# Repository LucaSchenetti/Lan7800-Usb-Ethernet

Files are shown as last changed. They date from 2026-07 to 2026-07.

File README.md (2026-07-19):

# USB SuperSpeed 3.1 → Gigabit Ethernet (LAN7800)

USB 3.1 Gen 1 (SuperSpeed, 5 Gbit/s) → Gigabit Ethernet adapter based on the
**Microchip LAN7800T/VSX** controller. The board has a **USB-C female** input
and a **USB-A male** output, so it works with both modern USB-C and traditional
USB-A ports. This repository contains the PCB design, production files, and
throughput test results measured with `iperf3`.

*(Versione italiana più in basso — [Italiano](#-adattatore-usb-superspeed-31--gigabit-ethernet-lan7800))*

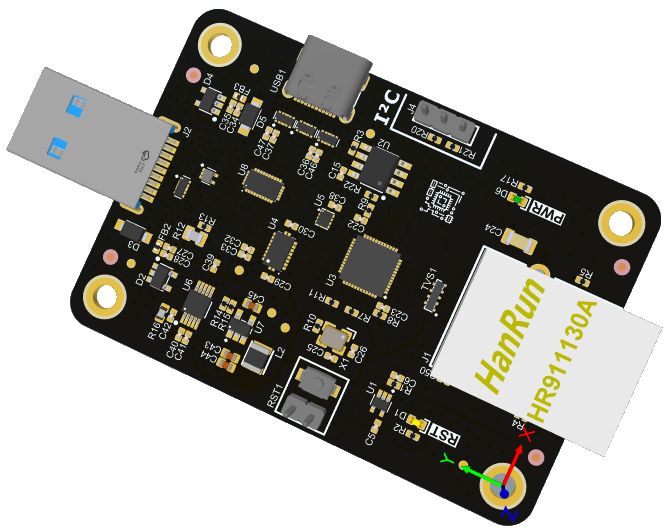
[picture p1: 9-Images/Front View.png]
Front render


## Features

- **Microchip LAN7800T/VSX** — USB 3.1 Gen 1 → 10/100/1000 Mbit/s Ethernet controller
- **USB-C female** input and **USB-A male** output — works with both modern
  USB-C ports and traditional USB-A ports
- **HanRun HR911130A** integrated RJ45 jack with magnetics
- Link negotiated at **1000 Mbit/s full-duplex**
- **Line-rate** throughput in both directions (see results below)
- On-board **reset button**, **power LED**, and an **I²C header** (SDA/SCL/GND)
- Bus-powered via USB
- Revision **C** (07/2026)

## Connectors and main components

The board accepts a **USB-C (female)** input and provides a **USB-A (male)**
output. The USB-C side includes full orientation/CC handling:

| Component | Function |
|---|---|
| Microchip **LAN7800T/VSX** | USB 3.1 Gen 1 → Gigabit Ethernet controller |
| Microchip **93AA66C-I/SN** | 4 Kbit serial EEPROM — stores the MAC address and USB configuration (VID/PID, descriptors) for the LAN7800 |
| TI **HD3SS3220RNHR** | USB-C mux/switch with CC logic — handles cable orientation and port role (DRP/DFP/UFP) for the USB-C connector |
| Diodes **PI3USB302-AZBEX** | USB Type-C SuperSpeed data demux/switch — routes the SS lines according to plug orientation |
| TI **TS3USB221ARSER** | USB 2.0 (high-speed) data mux/switch — routes the D+/D− lines according to plug orientation |
| HanRun **HR911130A** | Integrated RJ45 connector with Ethernet magnetics |

Additional on-board features: **RST** reset button, **PWR** power LED, and a
3-pin **I²C** header (SDA / SCL / GND) for debugging or expansion.

## Board

| Front (render) | Back (render) |
|:---:|:---:|
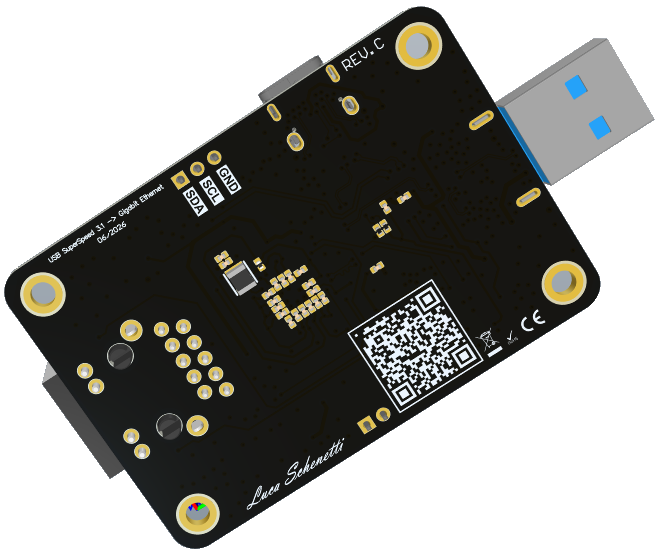
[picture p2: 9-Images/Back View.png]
Back render
| Front render |  |

| Front (photo) | Back (photo) |
|:---:|:---:|
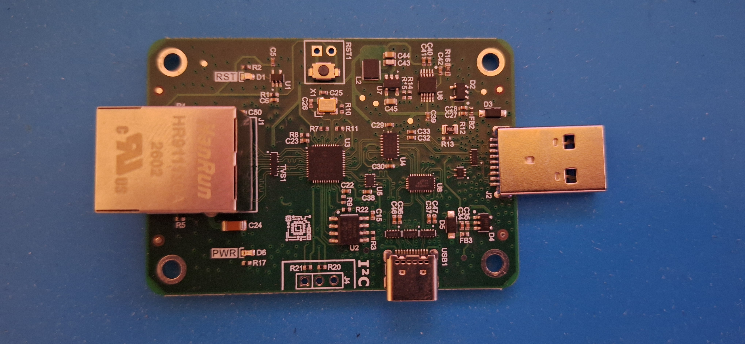
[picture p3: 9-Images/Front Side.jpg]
Front photo
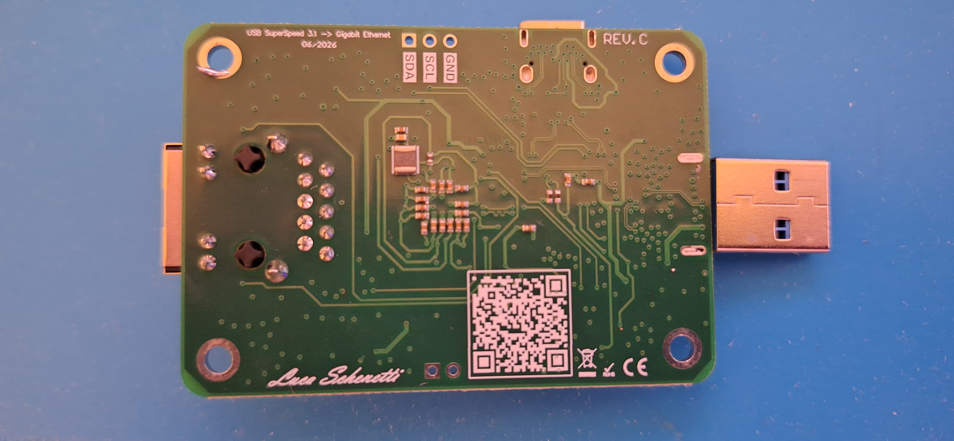
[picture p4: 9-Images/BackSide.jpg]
Back photo
|  |  |

## Test results (iperf3)

Tests were run with the [`iperf_benchmark.py`](8-Test_PCB/iperf_benchmark.py) script
included in this repository. The adapter reaches Gigabit Ethernet line rate
(~949 Mbit/s, the practical maximum with standard MTU due to protocol overhead)
in a stable way and with low host CPU usage.

### Windows 11 (bare-metal)

**Test host:** Windows 11 · iperf3 3.21 (64-bit) · server `11.0.0.91`
**Adapter:** LAN7800T/VSX · USB 3.1 · link 1000/full

| Test | Throughput | Notes |
|---|---|---|
| TCP unidirectional TX | 949 Mbit/s | min/max 947/950 · CPU client 3% / server 10% |
| TCP unidirectional RX | 949 Mbit/s | min/max 944/950 · CPU client 21% / server 7% |
| TCP 4 parallel streams | 949 Mbit/s | min/max 946/956 · CPU client 3% / server 12% |
| UDP (1000M) | 956 Mbit/s | jitter 0.02 ms · packet loss 0.06% |

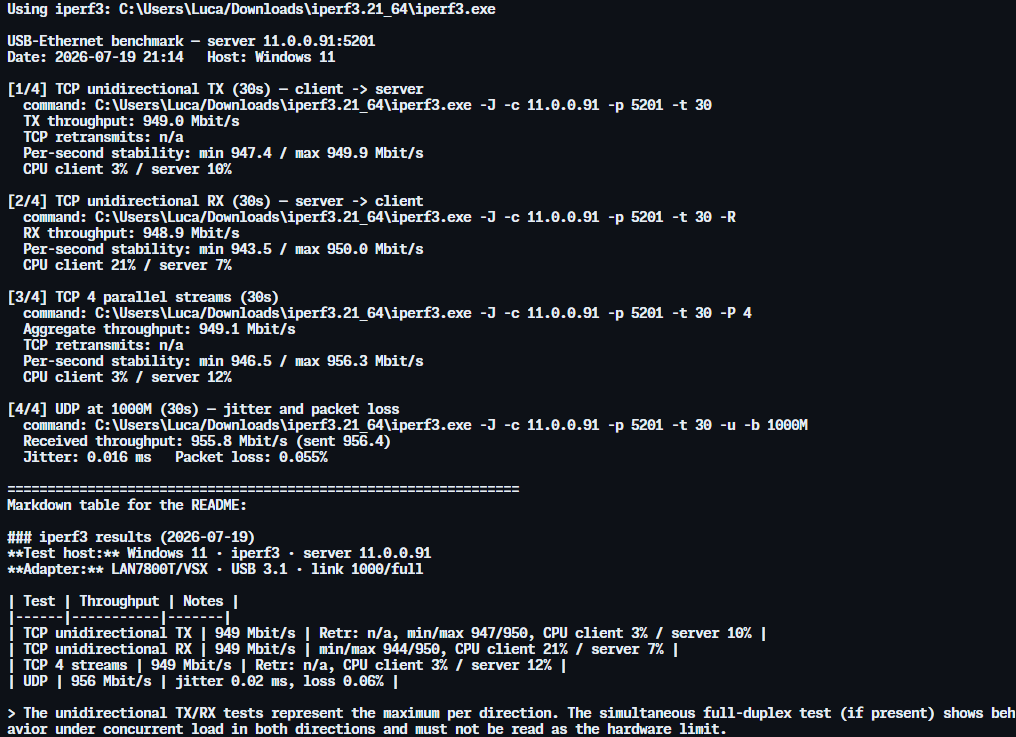
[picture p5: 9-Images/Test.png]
Benchmark output


**How to read the results:**

- **Unidirectional TX and RX** represent the maximum per single direction. Both
  are at line rate (~949 Mbit/s) and stable for the whole test duration, with no
  drop over time.
- **Low host CPU** (3–21%): throughput is not CPU-limited. USB→Ethernet adapters
  have no hardware offload, so this is a good efficiency indicator.
- **0.02 ms jitter** and **0.06% packet loss** on UDP saturated at 1 Gbit/s
  indicate an electrically clean link.
- TCP retransmits (`Retr`) are not reported on Windows because the field is not
  populated by the platform in the JSON output; this is normal and not a problem.

> **Note on simultaneous full-duplex:** a `--bidir` test (traffic in both
> directions at the same time) shows an asymmetry between TX and RX. This is the
> expected behavior of a USB→Ethernet adapter: without hardware offload, the two
> directions share the USB bus and CPU, and one prevails over the other under
> concurrent load. **This is not a hardware limit** — measured individually,
> both directions reach line rate, as shown in the table.

## Reproducing the tests

You need a second machine acting as the iperf3 server:

```bash
# On the server machine
iperf3 -s
```

```bash
# On the client machine (with the adapter under test)
python iperf_benchmark.py <SERVER_IP> --duration 30 --chip "LAN7800T/VSX · USB 3.1 · link 1000/full"
```

Useful options:

- `--duration N` — duration of the unidirectional TCP tests (default 60s)
- `--quick` — short 10s tests for a quick check
- `--bidir` — adds the simultaneous full-duplex test (extra, requires iperf3 ≥ 3.7)
- `--streams N` — number of parallel streams (default 4)
- `--iperf3 PATH` — path to the executable if not in PATH

The script prints the results and generates a Markdown table ready to paste.

### Notes on the test environment

For reliable numbers, run the tests from a **bare-metal operating system**, not
from a virtual machine. In a VM, hypervisor scheduling and virtual networking
can introduce throughput drops and asymmetries unrelated to the hardware under
test. The results above come from Windows 11 installed directly on the PC.

## Repository contents

```
Lan7800-Usb-Ethernet/
├── 1-Draw/                  Altium project — schematics (.SchDoc) and PCB layout (.PcbDoc)
├── 3-Gerber File & BOM/     Gerber files (Rev. A/B/C), BOM and pick-and-place (CPL)
├── 5-Driver/               EEPROM images (MAC address / USB configuration)
├── 7-Spec/                 Component datasheets (LAN7800, HD3SS3220, ...)
├── 8-Test_PCB/             iperf3 benchmark script and its README
├── 9-Images/               Board renders and photos
├── LICENSE
└── README.md
```

The Altium `History/` folder (automatic backups) is intentionally excluded via
`.gitignore` — it is not needed to build or use the project.

## License

Released under the **MIT License** — see the [LICENSE](LICENSE) file for details.

---
---

# 🇮🇹 Adattatore USB SuperSpeed 3.1 → Gigabit Ethernet (LAN7800)

Adattatore USB 3.1 Gen 1 (SuperSpeed, 5 Gbit/s) → Gigabit Ethernet basato sul
controller **Microchip LAN7800T/VSX**. La scheda ha un ingresso **USB-C
femmina** e un'uscita **USB-A maschio**, quindi funziona sia su porte USB-C
moderne sia su porte USB-A tradizionali. Questo repository contiene il progetto
del PCB, i file di produzione e i risultati dei test di throughput eseguiti con
`iperf3`.

*(English version above — [English](#usb-superspeed-31--gigabit-ethernet-lan7800))*

Render fronte

## Caratteristiche

- **Microchip LAN7800T/VSX** — controller USB 3.1 Gen 1 → 10/100/1000 Mbit/s Ethernet
- Ingresso **USB-C femmina** e uscita **USB-A maschio** — utilizzabile sia su
  porte USB-C moderne sia su porte USB-A tradizionali
- Connettore RJ45 integrato con magnetics **HanRun HR911130A**
- Link negoziato a **1000 Mbit/s full-duplex**
- Throughput a **line rate** in entrambe le direzioni (vedi risultati sotto)
- **Pulsante di reset**, **LED di alimentazione** e **header I²C** (SDA/SCL/GND) a bordo
- Alimentazione via bus USB
- Revisione **C** (06/2026)

## Connettori e componenti principali

La scheda accetta un ingresso **USB-C (femmina)** e fornisce un'uscita **USB-A
(maschio)**. Il lato USB-C include la gestione completa dell'orientamento/CC:

| Componente | Funzione |
|---|---|
| Microchip **LAN7800T/VSX** | Controller USB 3.1 Gen 1 → Gigabit Ethernet |
| Microchip **93AA66C-I/SN** | EEPROM seriale da 4 Kbit — memorizza il MAC address e la configurazione USB (VID/PID, descrittori) per il LAN7800 |
| TI **HD3SS3220RNHR** | Mux/switch USB-C con logica CC — gestisce l'orientamento del cavo e il ruolo della porta (DRP/DFP/UFP) per il connettore USB-C |
| Diodes **PI3USB302-AZBEX** | Demux/switch dati SuperSpeed USB Type-C — instrada le linee SS in base all'orientamento del connettore |
| TI **TS3USB221ARSER** | Mux/switch dati USB 2.0 (high-speed) — instrada le linee D+/D− in base all'orientamento del connettore |
| HanRun **HR911130A** | Connettore RJ45 integrato con magnetics Ethernet |

Altre feature a bordo: pulsante di reset **RST**, LED di alimentazione **PWR** e
un header **I²C** a 3 pin (SDA / SCL / GND) per debug o espansione.

## Scheda

| Fronte (render) | Retro (render) |
|:---:|:---:|
| Render fronte | Render retro |

| Fronte (foto) | Retro (foto) |
|:---:|:---:|
| Foto fronte | Foto retro |

## Risultati dei test (iperf3)

I test sono stati eseguiti con lo script [`iperf_benchmark.py`](8-Test_PCB/iperf_benchmark.py)
incluso nel repository. L'adattatore raggiunge il line rate di Gigabit Ethernet
(~949 Mbit/s, il massimo pratico con MTU standard per via dell'overhead di
protocollo) in modo stabile e con CPU dell'host bassa.

### Windows 11 (bare-metal)

**Host di test:** Windows 11 · iperf3 3.21 (64-bit) · server `11.0.0.91`
**Adattatore:** LAN7800T/VSX · USB 3.1 · link 1000/full

| Test | Throughput | Note |
|---|---|---|
| TCP unidirezionale TX | 949 Mbit/s | min/max 947/950 · CPU client 3% / server 10% |
| TCP unidirezionale RX | 949 Mbit/s | min/max 944/950 · CPU client 21% / server 7% |
| TCP 4 stream paralleli | 949 Mbit/s | min/max 946/956 · CPU client 3% / server 12% |
| UDP (1000M) | 956 Mbit/s | jitter 0.02 ms · packet loss 0.06% |

Output benchmark

**Lettura dei risultati:**

- **TX e RX unidirezionali** rappresentano il massimo per singola direzione.
  Entrambi sono a line rate (~949 Mbit/s) e stabili per tutta la durata del
  test, senza cali nel tempo.
- **CPU dell'host bassa** (3–21%): il throughput non è limitato dalla CPU, e gli
  adattatori USB→Ethernet non dispongono di offload hardware, quindi questo è un
  buon indicatore di efficienza.
- **Jitter di 0.02 ms** e **packet loss dello 0.06%** su UDP saturato a 1 Gbit/s
  indicano un link elettricamente pulito.
- Le ritrasmissioni TCP (`Retr`) non sono riportate su Windows perché il campo
  non viene popolato dalla piattaforma nell'output JSON; è normale e non indica
  un problema.

> **Nota sul full-duplex simultaneo:** un test `--bidir` (traffico in entrambe le
> direzioni contemporaneamente) mostra un'asimmetria tra TX e RX. Questo è il
> comportamento atteso di un adattatore USB→Ethernet: senza offload hardware, le
> due direzioni condividono bus USB e CPU e una prevale sull'altra sotto carico
> simultaneo. **Non è un limite dell'hardware** — misurate singolarmente,
> entrambe le direzioni raggiungono il line rate, come mostrato nella tabella.

## Riprodurre i test

Serve una seconda macchina che faccia da server iperf3:

```bash
# Sulla macchina server
iperf3 -s
```

```bash
# Sulla macchina client (con l'adattatore da testare)
python iperf_benchmark.py <IP_SERVER> --duration 30 --chip "LAN7800T/VSX · USB 3.1 · link 1000/full"
```

Opzioni utili:

- `--duration N` — durata dei test TCP unidirezionali (default 60s)
- `--quick` — test brevi da 10s per una prova rapida
- `--bidir` — aggiunge il test full-duplex simultaneo (extra, richiede iperf3 ≥ 3.7)
- `--streams N` — numero di stream paralleli (default 4)
- `--iperf3 PERCORSO` — percorso dell'eseguibile se non è nel PATH

Lo script stampa i risultati e genera una tabella Markdown pronta da incollare.

### Note sull'ambiente di test

Per numeri affidabili, esegui i test da **sistema operativo bare-metal**, non da
una macchina virtuale. In una VM lo scheduling dell'hypervisor e il networking
virtuale possono introdurre cali di throughput e asimmetrie che non dipendono
dall'hardware testato. I risultati qui sopra provengono da Windows 11 installato
direttamente sul PC.

## Contenuto del repository

```
Lan7800-Usb-Ethernet/
├── 1-Draw/                  Progetto Altium — schematici (.SchDoc) e layout PCB (.PcbDoc)
├── 3-Gerber File & BOM/     File Gerber (Rev. A/B/C), BOM e pick-and-place (CPL)
├── 5-Driver/               Immagini EEPROM (MAC address / configurazione USB)
├── 7-Spec/                 Datasheet dei componenti (LAN7800, HD3SS3220, ...)
├── 8-Test_PCB/             Script di benchmark iperf3 e relativo README
├── 9-Images/               Render e foto della scheda
├── LICENSE
└── README.md
```

La cartella Altium `History/` (backup automatici) è volutamente esclusa tramite
`.gitignore` — non serve per costruire o usare il progetto.

## Licenza

Distribuito con **licenza MIT** — vedi il file [LICENSE](LICENSE) per i dettagli.

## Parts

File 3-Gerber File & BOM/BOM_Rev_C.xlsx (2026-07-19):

Comment | Designator | Footprint | JLCPCB Part #（optional）
100n | C1, C2, C3, C4, C5, C6, C7, C8, C9, C10, C11, C12, C15, C16, C17, C20, C21, C22, C29, C30, C31, C32, C33, C36, C37, C38, C39, C40, C41, C42, C46, C47, C48, C49, C50 | CAP_0402 | C307331
22u | C13 | CAP_0402 | C415703
1u | C14, C18, C19, C23 | CAP_0402 | C52923
10n | C24 | CAP_1206 | C1846
15p | C25, C26 | CAP_0402 | C1548
2u2 | C27, C28, C34, C35 | CAP_0402 | C12530
12p | C43 | CAP_0603 | C38523
22uF | C44, C45 | CAP_0603 | C59461
YELLOW | D1 | LED_0603_YELLOW | C89811
IDEAL DIODE 1A | D2, D4 | MAX40200AUK+T | C2649430
ESD Protection TVS 6.0V | D3, D5 | SMF6.0CA | C123791
GREEN | D6 | LED_0603_GREEN | C2986059
120R | FB1, FB2, FB3 | FB_0402 | C76891
100/1000Base-T RJ45 MAGJACK | J1 | HR911130A | C54408
USB-A MALE 9P | J2 | HC-USB3.0-C26 | C7501854
3u3 | L1 | INDUCTOR 1210 | C2047622
4.7uH | L2 | INDUCTOR 1210 | C5832387
1k | R1, R2, R17 | RES_0402 | C11702
10k | R3, R7, R9, R19, R22 | RES_0402 | C25744
510R | R4, R5 | RES_0402 | C25123
2K | R8 | RES_0402 | C4109
0R | R10 | RES_0402 | C17168
12K | R11 | RES_0402 | C25752
900K | R12 | RES_0805 | C52209984
4K7 | R13, R20, R21 | RES_0402 | C25900
450k | R14 | RES_0402 | C5159688
100k | R15 | RES_0402 | C25741
10K | R16 | RES_0603 | C25804
200K | R18 | RES_0402 | C25764
RST_SWITCH_STM32 | RST1 | RST_SWITCH | C720477
8-Line Ultra Low Capacitance TVS Diode Array | TVS1 | RCLAMP3328P | C28646386
TVS DIODE USB 3 | TVS2, TVS5, TVS6 | TPD4E02B04DQAR | C106794
ESD and Surge Protection USB, HDMI & High Speed | TVS3 | TPD4E05U06DQAR | C138714
TVS USB 2.0 ±25-kV | TVS4 | TPD2E2U06DRLR | C1972959
Schmitt Trigger 1.65V~5.5V | U1 | 74LVC1G14GW,125 | C265125
EEPROM 1.8V~5.5V 4Kbit SPI | U2 | 93AA66C-I/SN | C153277
ETH-USB 3.1 | U3 | LAN7800T/VSX | C625082
MUX USB 3.0 | U4 | PI3USB302-AZBEX | C500787
MUX USB2.0 | U5 | TS3USB221ARSER | C128396
Analog Switches, Multiplexers | U6 | TS5A23157DGSR | C11133
BUCK CONVERTER 1A 2.5V~5.5V | U7 | TLV62568DBVR | C163219
USB Type-C MUX CONTROLLER | U8 | HD3SS3220 | C165155
USB-C 24P SMD | USB1 | TYPE-C 24P QT 143 | C5156605
25MHz | X1 | XTAL_3225 | C9006

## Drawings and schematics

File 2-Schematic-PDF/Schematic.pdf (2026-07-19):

5

6

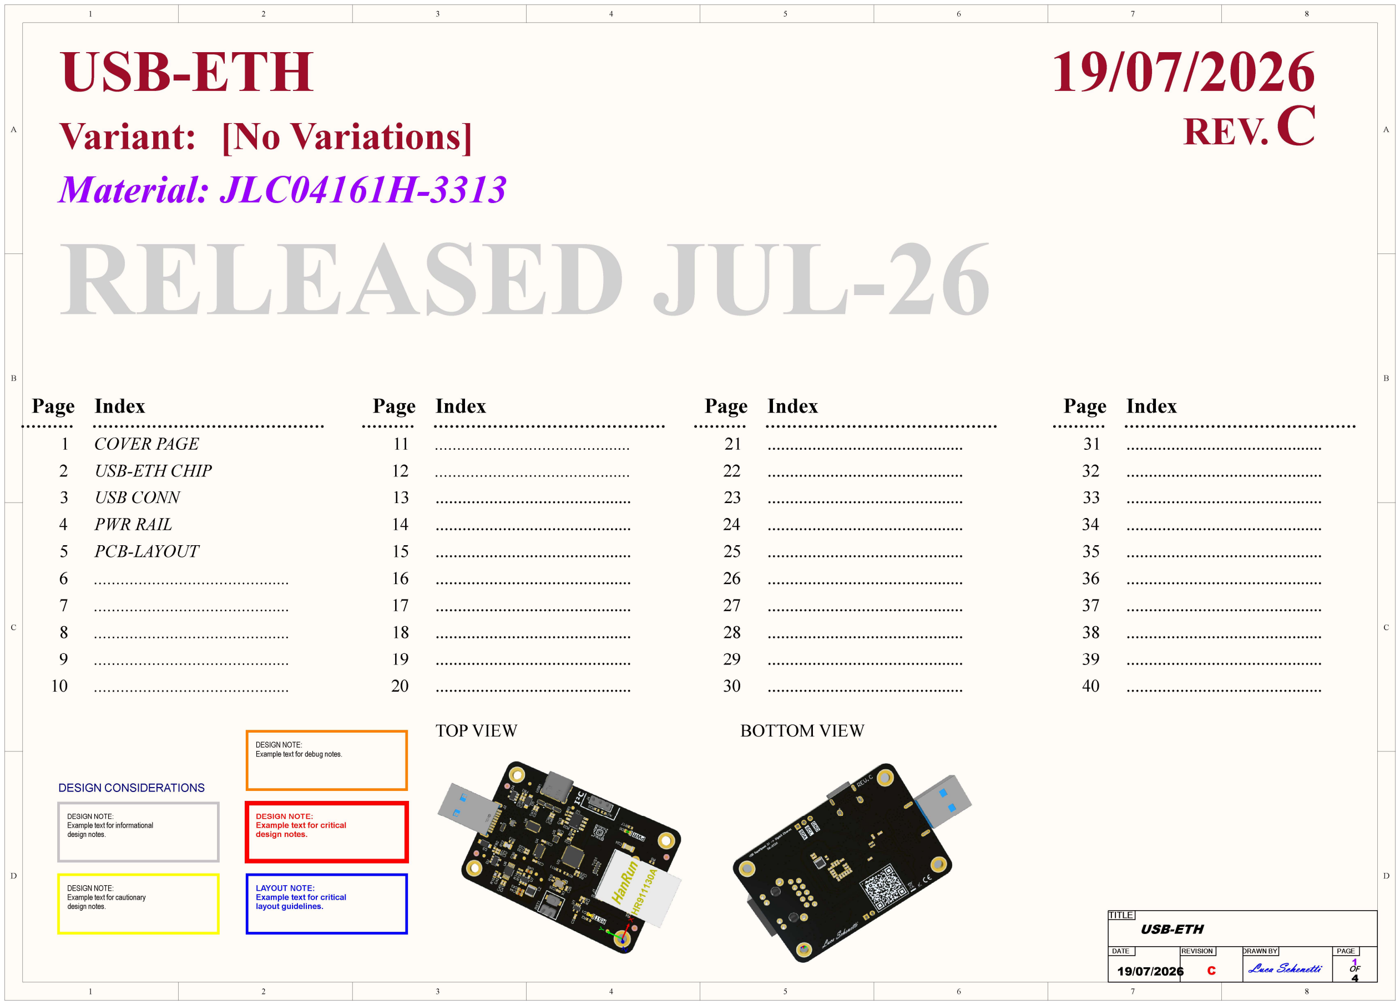
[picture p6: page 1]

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
USB-ETH | 19/07/2026
Variant: [No Variations] | C

# RELEASED JUL-26

# Page Index

# 1 COVER PAGE 2 USB-ETH CHIP 3 USB CONN 4 PWR RAIL 5 PCB-LAYOUT

6

7

8

9
10

# Page Index

11
12 |
13 |
14 |
15 |
16 |
17 |
18 |
19 |
20 |

# Page Index

21 |
22 |
23 |
24 |
25 |
26 |
27 |
28 |
29 |
30 |

# Page Index

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
## DESIGN NOTE: Example text for cautionary

design notes.

## DESIGN NOTE: Example text for informational

design notes.

# DESIGN CONSIDERATIONS

## DESIGN NOTE: Example text for critical

design notes.

## LAYOUT NOTE: Example text for critical

layout guidelines.

## DESIGN NOTE:

Example text for debug notes.

TOP VIEW | BOTTOM VIEW

# TITLE

DATE | REVISION | DRAWN BY | PAGE

# USB-ETH

19/07/2026

OF

# C Luca Schenetti

# Material: JLC04161H-3313

REV.

# RESET CIRCUIT

# EEPROM

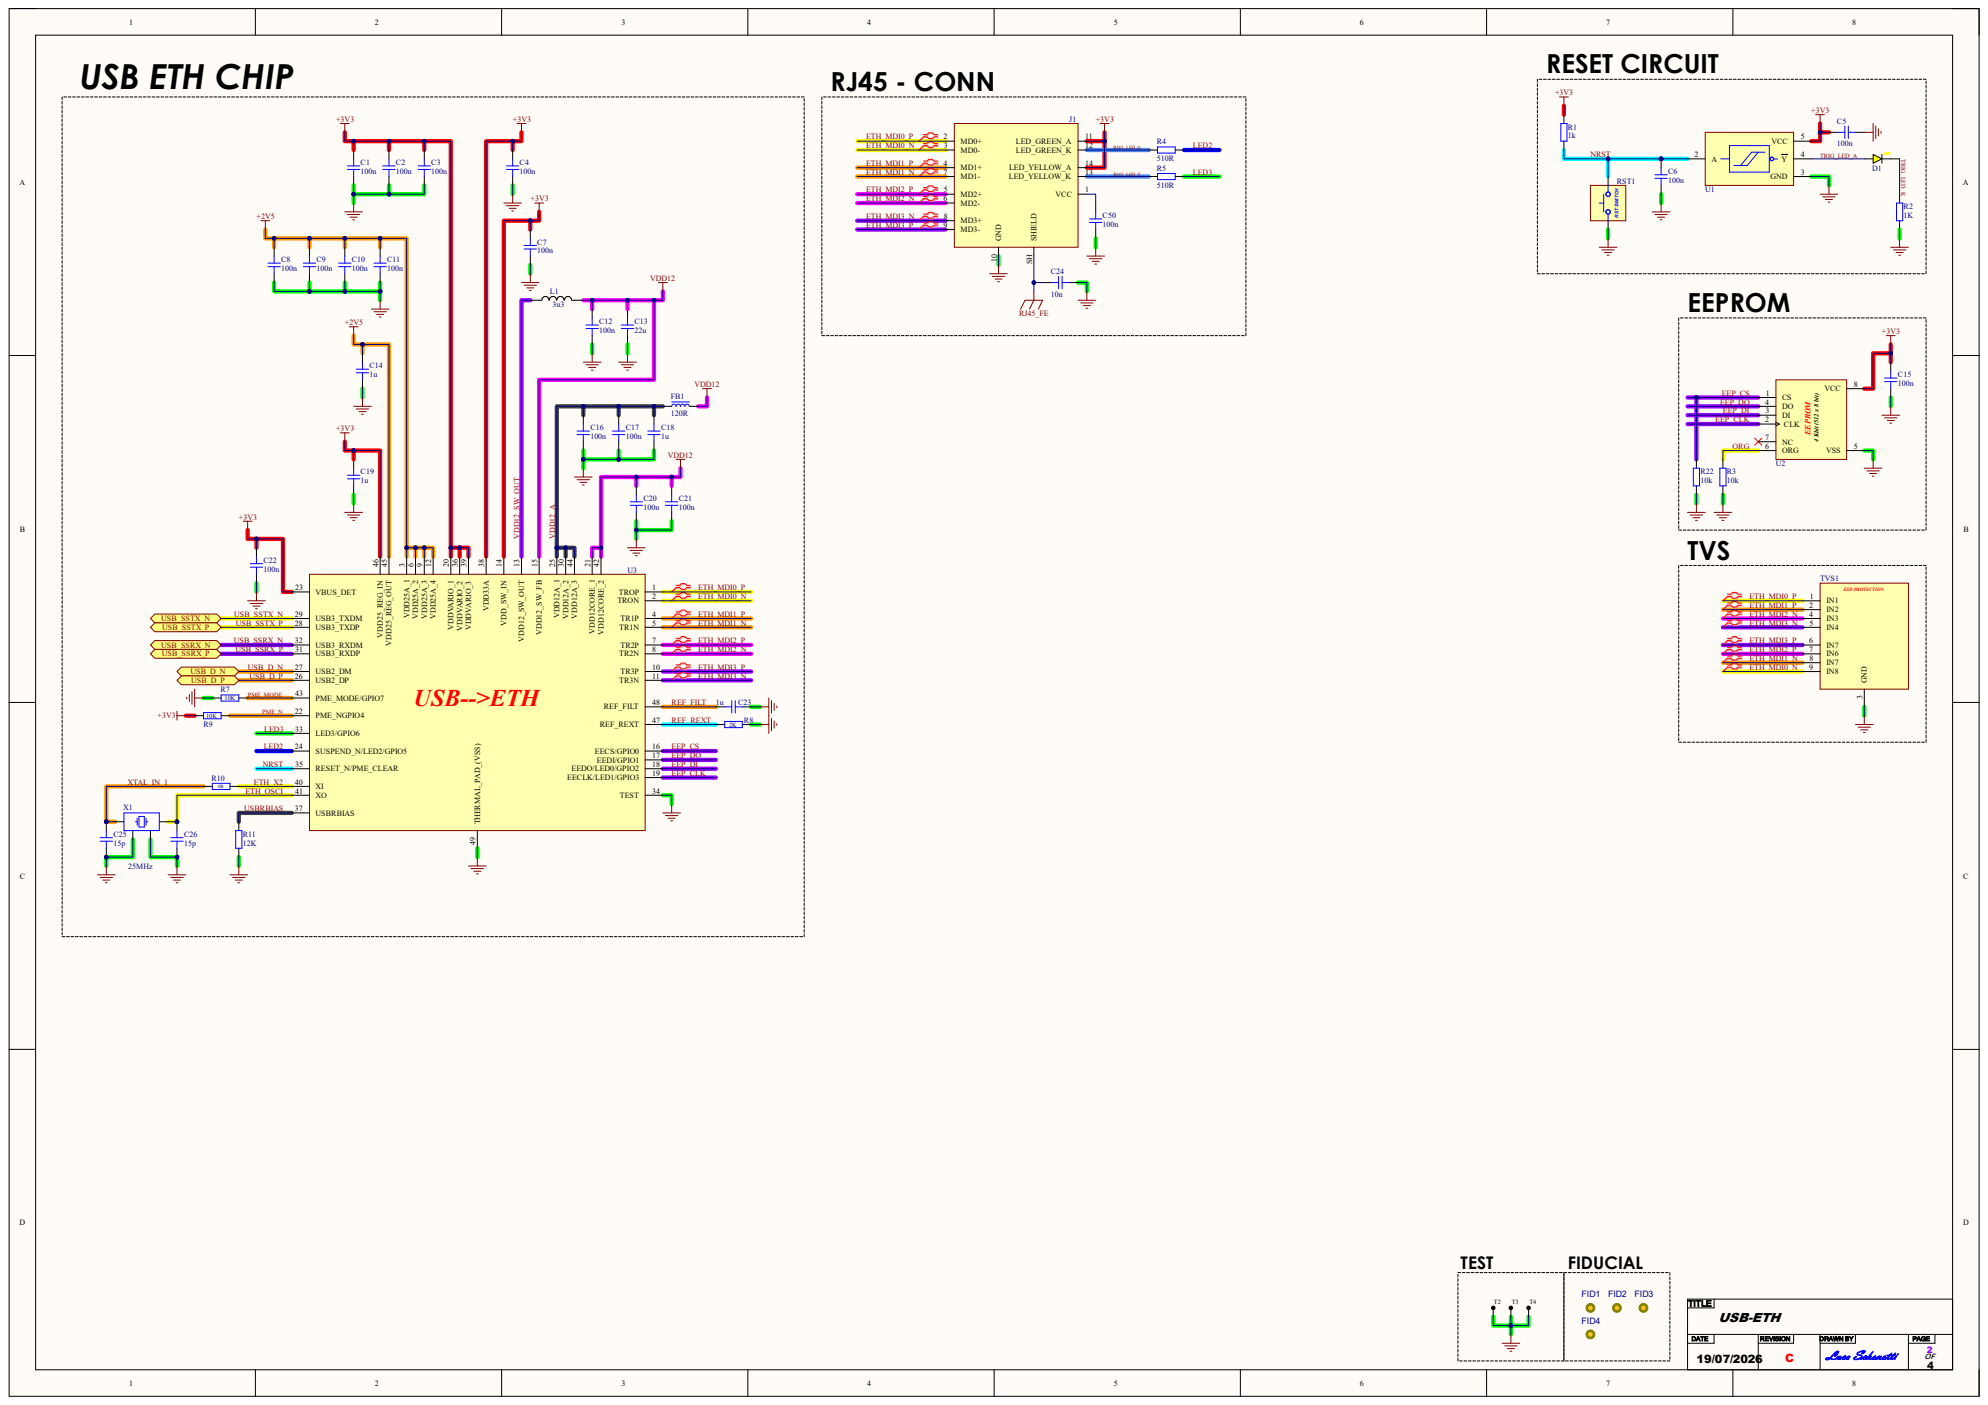
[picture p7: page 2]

TX2+ 15 | TX2- 14 | VDD ¹ VDD ⁶ VDD ¹⁰

# USB-A CONN

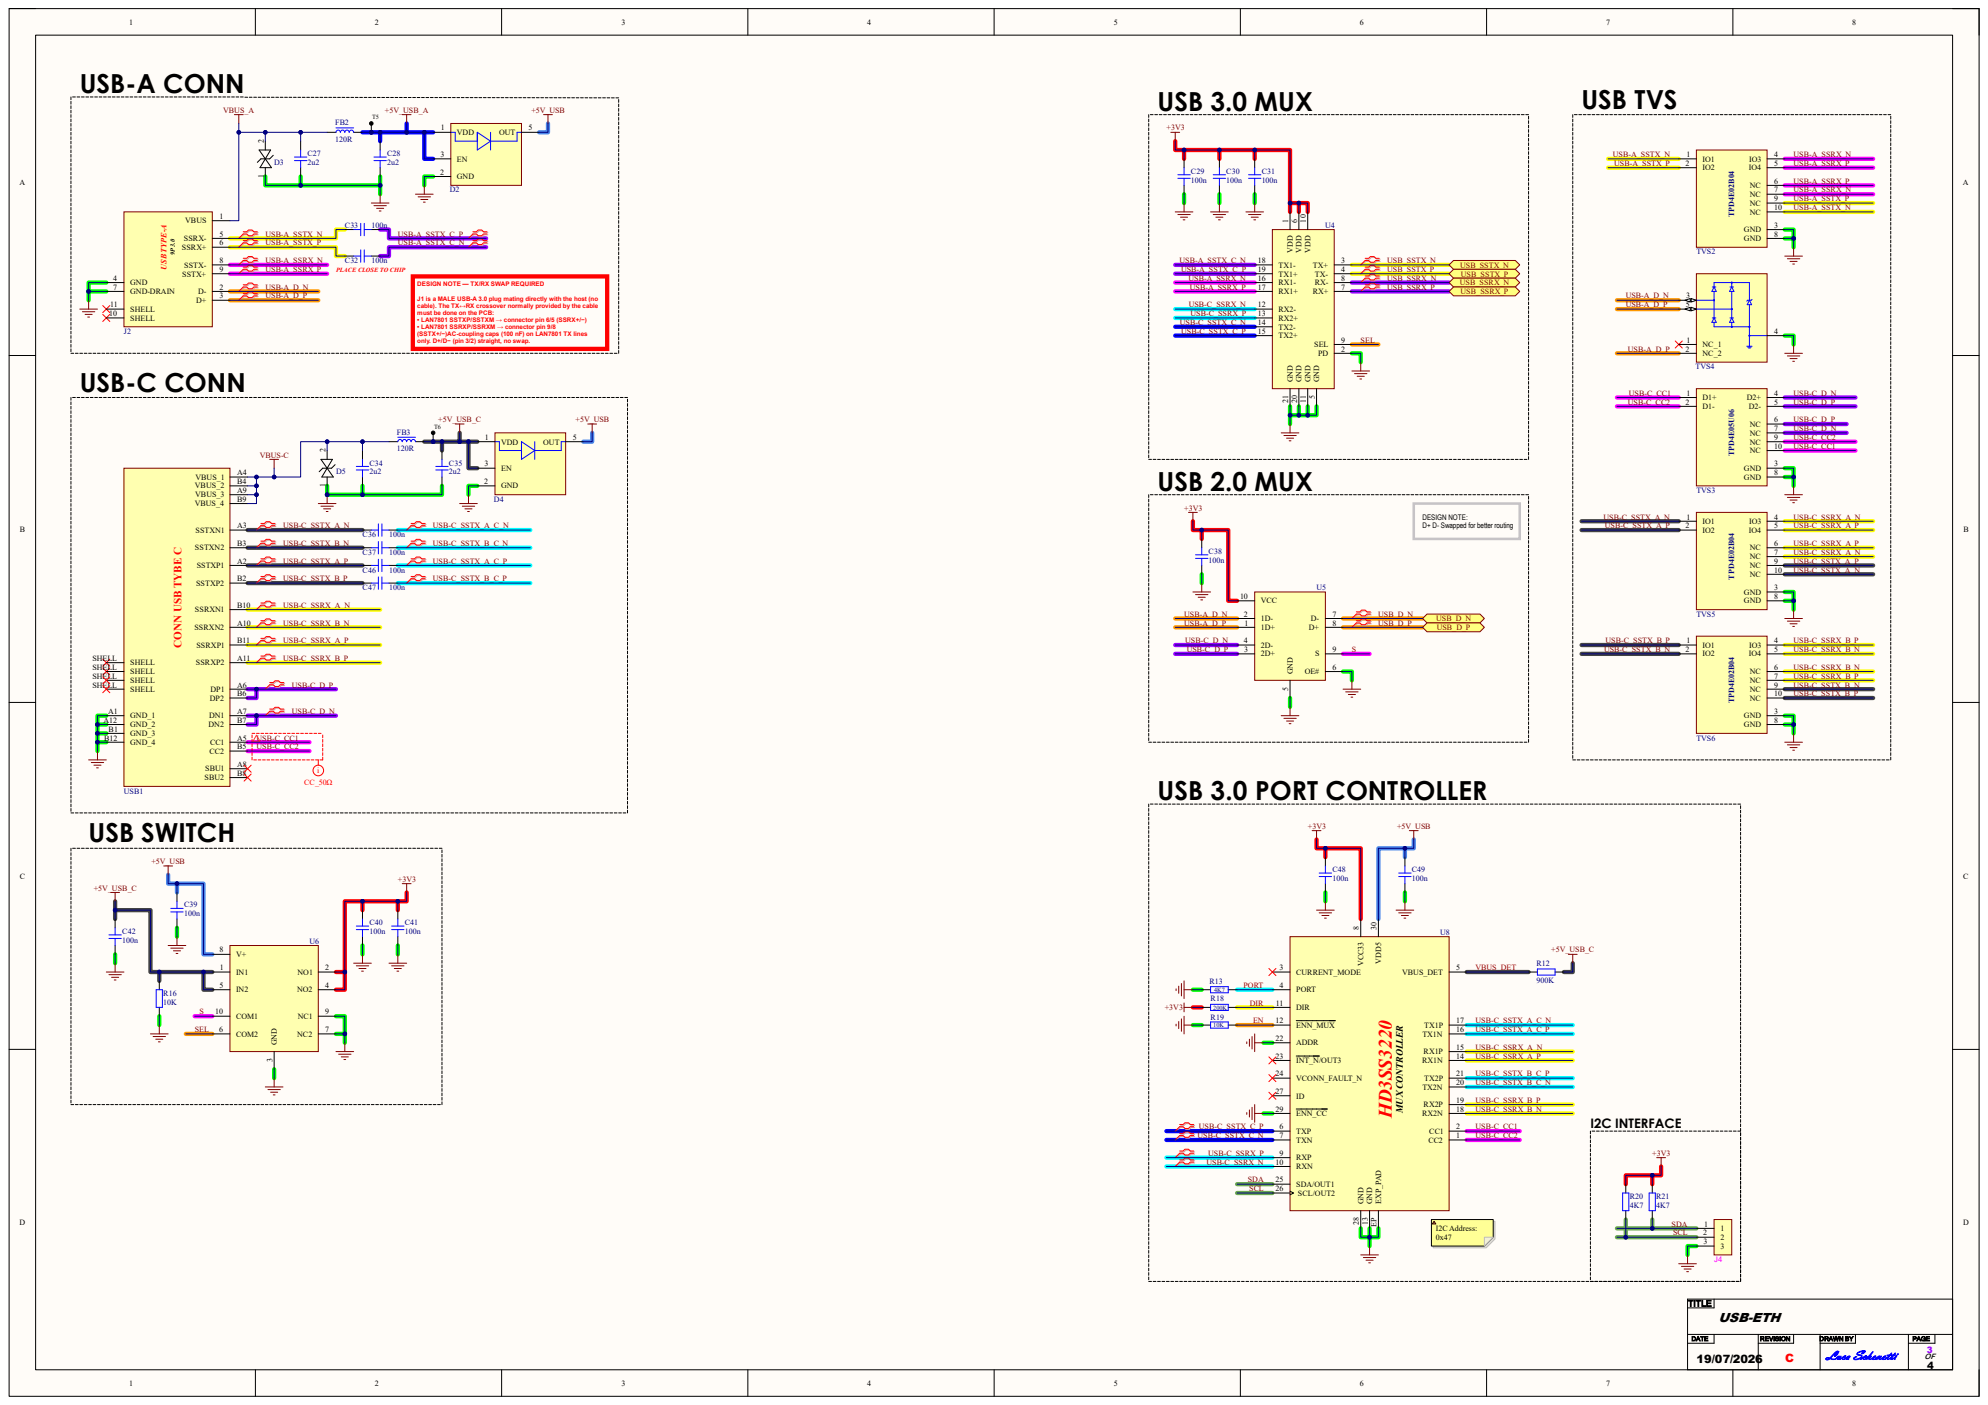
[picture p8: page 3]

PLACE CLOSE TO CHIP

DESIGN NOTE — TX/RX SWAP REQUIRED

J1 is a MALE USB-A 3.0 plug mating directly with the host (no
cable). The TX↔RX crossover normally provided by the cable
must be done on the PCB:
• LAN7801 SSTXP/SSTXM → connector pin 6/5 (SSRX+/−)
• LAN7801 SSRXP/SSRXM → connector pin 9/8
(SSTX+/−)AC-coupling caps (100 nF) on LAN7801 TX lines
only. D+/D− (pin 3/2) straight, no swap.

DESIGN NOTE:
D+ D- Swapped for better routing

A A

# STEP DOWN REG

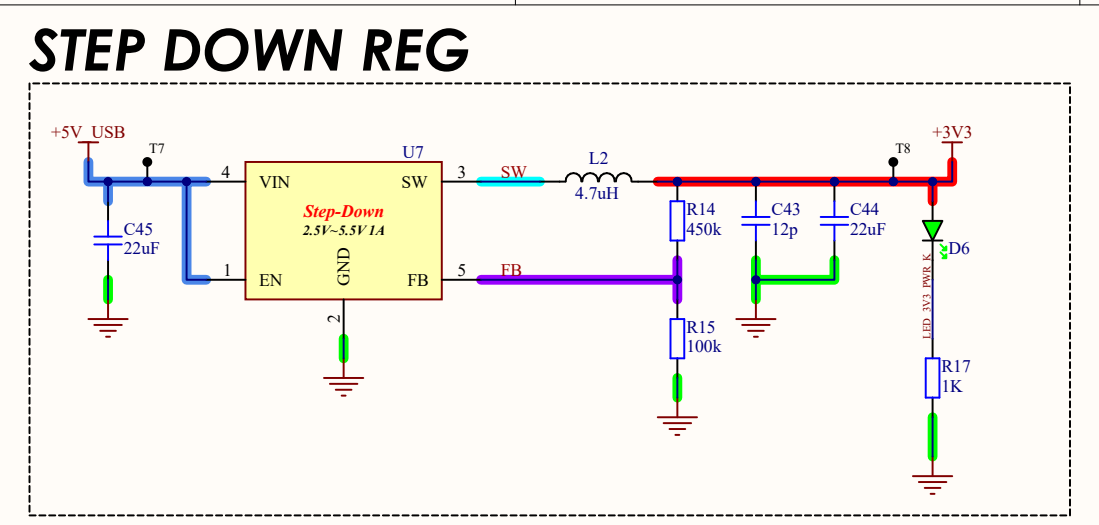
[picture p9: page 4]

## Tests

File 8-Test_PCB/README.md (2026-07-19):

# USB-Ethernet Adapter Benchmark (iperf3)

A single-file Python script that benchmarks USB → Ethernet adapters with
[iperf3](https://github.com/esnet/iperf) and prints the results both to the
terminal and as a Markdown table ready to paste into a README.

## Why a dedicated script?

On USB adapters the interesting questions are not just "how fast is it":

- **TX and RX are measured separately** with unidirectional runs. Without
  hardware offload, simultaneous full-duplex makes the two directions compete
  for the USB bus and CPU, giving misleading per-direction numbers.
- **CPU usage (client and server) is reported** — on USB adapters the host is
  often the limiting factor, not the adapter itself.
- **UDP reports the *received* throughput**, not the send rate, together with
  jitter and packet loss.
- Per-second min/max is shown for every TCP test to spot instability
  (bus contention, driver issues, thermal throttling).

## Requirements

- Python 3.7+ (no third-party packages)
- iperf3 on the client, either in `PATH` or passed with `--iperf3`
  (on Windows the script also looks in `~/Downloads`, `C:\iperf3` and
  `C:\Program Files\iperf3`)
- an iperf3 server running on the other machine: `iperf3 -s`
- for the optional `--bidir` test: iperf3 ≥ 3.7 on both ends

## Usage

```console
python iperf_benchmark.py <SERVER_IP> [options]
```

| Option | Description |
|---|---|
| `--port N` | server port (default 5201) |
| `--duration N` | duration of the unidirectional TCP tests in seconds (default 60) |
| `--udp-bandwidth B` | target bandwidth of the UDP test (default `1000M`) |
| `--streams N` | number of parallel TCP streams (default 4) |
| `--quick` | short 10 s tests for a quick check |
| `--bidir` | add the simultaneous full-duplex test (extra) |
| `--chip NAME` | adapter description shown in the Markdown table |
| `--iperf3 PATH` | path to the iperf3 executable if not in `PATH` |

Example:

```console
python iperf_benchmark.py 192.168.1.10 --duration 30 --chip "LAN7800T/VSX · USB 3.1 · link 1000/full"
```

## Example results

### iperf3 results (2026-07-19)
**Test host:** Windows 11 · iperf3 · server on a gigabit LAN
**Adapter:** LAN7800T/VSX · USB 3.1 · link 1000/full

| Test | Throughput | Notes |
|---|---|---|
| TCP unidirectional TX | 949 Mbit/s | Retr: n/a, min/max 935/950, CPU client 3% / server 10% |
| TCP unidirectional RX | 948 Mbit/s | min/max 936/950, CPU client 20% / server 6% |
| TCP 4 streams | 949 Mbit/s | Retr: n/a, CPU client 3% / server 13% |
| UDP | 952 Mbit/s | jitter 0.01 ms, loss 0.42% |

> The unidirectional TX/RX tests represent the maximum per direction. The
> simultaneous full-duplex test (if present) shows behavior under concurrent
> load in both directions and must not be read as the hardware limit.

~949 Mbit/s is the theoretical TCP payload limit of Gigabit Ethernet with a
1500-byte MTU: this adapter saturates the link in both directions.

## Reading the numbers

- **TCP unidirectional TX/RX** — the real maximum of each direction.
- **TCP N streams** — aggregate maximum of the link; if it is much higher
  than the single stream, the bottleneck is per-connection, not the adapter.
- **UDP** — link quality: jitter and packet loss at the target rate. Small
  loss at full line rate is expected (the send rate slightly exceeds what the
  link can carry).
- **Simultaneous full-duplex** (`--bidir`) — behavior under concurrent load
  in both directions. On USB adapters the two directions share bus and CPU,
  so these numbers are *not* per-direction maximums.

## License

[MIT](LICENSE)

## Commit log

2026-07-19 Initial commit
    LAN7800 USB SuperSpeed 3.1 to Gigabit Ethernet adapter — Altium project, Rev. C gerbers/BOM, EEPROM images, datasheets, board photos and iperf3 benchmark results.
    [BOM_Rev_C.xlsx, COVER PAGE.SchDoc, PWR RAIL.SchDoc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]
2026-07-19 Add schematic PDF export
    Add schematics exported to PDF for viewing without Altium
    [COVER PAGE.SchDoc, USB CONN.SchDoc, USB-ETH CHIP.SchDoc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]
